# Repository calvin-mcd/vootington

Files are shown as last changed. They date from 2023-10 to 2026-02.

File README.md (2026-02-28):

# Vootington

The Vootington is an open source hall-effect pcb for the V4N keyboard.

The aim of this project is to offer a functional hardware Hall-effect reference project for the community. The project is not meant to offer the full aspects of firmware. I leave that to smart people to figure out.

The keyboard takes design cues from the Wooting keyboards, [the moonpad](https://github.com/RephlexZero/MoonPad) and [the void switch keyboards](https://github.com/riskable/void_switch_65_pct) from riskable.

## Layout

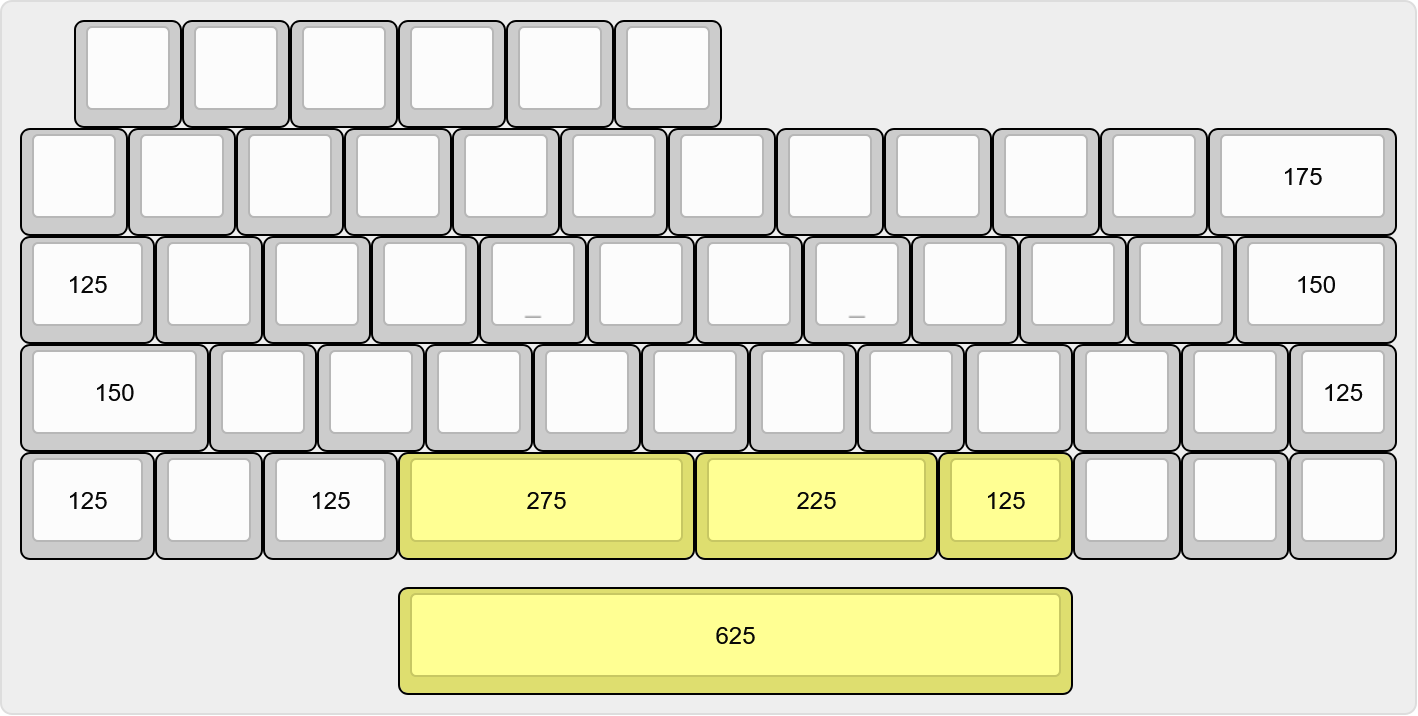
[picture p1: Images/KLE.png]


[Link](http://www.keyboard-layout-editor.com/#/gists/a01bb022278fa95758b773367ecef891)

## Firmware

The basic firmware included in the folder is experimental and designed by KarlK90. Their work can be found here:
https://github.com/KarlK90/qmk_firmware/tree/feature/vootington/keyboards/calvin0563/vootington

Pete is currently developing more advanced HE firmware for zmk. Keep your eyes on that:
https://github.com/petejohanson/vootington-zmk-config

**beware!!!**

The hardware configuration for rgb on the vootington is currently not supported by zmk, which means no rgb with the zmk firmware.

## Todo

- [ ] create advanced firmware with full HE functionality

## Disclaimer

This PCB has been fully tested and is confirmed to work. However, no-one involved in this project is responsible for any usage issues that may arise. Order at your own risk. Feel free to edit, modify and otherwise utilise these files.

## License

This project is released under the GPL v3 License. Please refer to the LICENCE file.

## Credits

big thanks to KarlK90 for making the initial firmware and for supporting the hardware design of the keyboard.

another huge thanks to pete for writing zmk firmware for this!

As always big thanks also to the many people who helped to inspire this board!

Any questions, contact Calvin0563 on Discord.

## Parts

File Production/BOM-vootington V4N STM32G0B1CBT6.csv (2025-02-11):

Comment | Designator | Footprint | LCSC | Quantity
330 Ohm | R4 | R_0402_1005Metric | C105875 | 1
1uF | C55 | C_0402_1005Metric | C106254 | 1
Alps SKRK | SW1,SW2 | SW_Push_SPST_NO_Alps_SKRK | C115351 | 2
1k OHM 100mhz | FB1 | Fuse_0402_1005Metric | C1236503 | 1
33 Ohm | R1,R2 | R_0402_1005Metric | C137880 | 2
10nF | C54 | C_0402_1005Metric | C1524 | 1
JST SH | J3 | JST_SH_SM04B-SRSS-TB_1x04-1MP_P1.00mm_Horizontal | C160404 | 1
10k | R3,R5,R6 | R_0402_1005Metric | C25744 | 3
5.1k | R7,R8 | R_0402_1005Metric | C25905 | 2
PRTR5V0U2X | U55 | SOT-143 | C2827688 | 1
STM32G0B1CBTx | U53 | LQFP-48_7x7mm_P0.5mm | C2847904 | 1
AP40P05 | Q1 | SOT-23 | C2886385 | 1
SLSS49E-3 | U1,U10,U11,U12,U13,U14,U15,U16,U17,U18,U19,U2,U20,U21,U22,U23,U24,U25,U26,U27,U28,U29,U3,U30,U31,U32,U33,U34,U35,U36,U37,U38,U39,U4,U40,U41,U42,U43,U44,U45,U46,U47,U48,U49,U5,U50,U51,U52,U6,U7,U8,U9 | SOT-23 | C2904393 | 52
SMF9.0CA | D_PWR1 | D_SOD-123 | C2980405 | 1
USB_C sink board 1.3mm | J2 | USB_C_Receptacle_HRO_TYPE-C-31-M-12 | C3019717 | 1
AP2112K-3.3 | U54 | SOT-23-5 | C3021085 | 1
100nF | C1,C10,C100,C101,C102,C103,C104,C105,C106,C107,C108,C109,C11,C110,C111,C112,C113,C114,C115,C116,C117,C118,C119,C12,C120,C121,C122,C123,C124,C13,C14,C15,C16,C17,C18,C19,C2,C20,C21,C22,C23,C24,C25,C26,C27,C28,C29,C3,C30,C31,C32,C33,C34,C35,C36,C37,C38,C39,C4,C40,C41,C42,C43,C44,C45,C46,C47,C48,C49,C5,C50,C51,C52,C53,C56,C6,C61,C62,C63,C64,C65,C66,C67,C68,C69,C7,C70,C71,C72,C73,C74,C75,C76,C77,C78,C79,C8,C80,C81,C82,C83,C84,C85,C86,C87,C88,C89,C9,C90,C91,C92,C93,C94,C95,C96,C97,C98,C99 | C_0402_1005Metric | C307331 | 118
YS-SK6803MINI-E | D1,D10,D11,D12,D13,D14,D15,D16,D17,D18,D19,D2,D20,D21,D22,D23,D24,D25,D26,D27,D28,D29,D3,D30,D31,D32,D33,D34,D35,D36,D37,D38,D39,D4,D40,D41,D42,D43,D44,D45,D46,D47,D48,D49,D5,D50,D51,D52,D53,D54,D55,D6,D7,D8,D9 | SK6803-MINI-E | C5242955 | 55
10uF | C57,C58,C59,C60 | C_0402_1005Metric | C52923 | 4
74HC4051 | U57,U58,U59,U60,U61,U62,U63 | TSSOP16 | C5645 | 7
500mA | F1 | Fuse_1206_3216Metric | C70076 | 1
74AHCT1G125 | U56 | TSOT-23-5 | C7468 | 1

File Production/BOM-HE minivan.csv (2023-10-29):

Comment | Designator | Footprint | LCSC
SKQGABE010 | SW1 | SW_SPST_SKQG_WithoutStem | C115351
ASMD1206-150 | F2 | Fuse_1206_3216Metric | C135341
JST SH | J1 | JST_SH_SM04B-SRSS-TB_1x04-1MP_P1.00mm_Horizontal | C160404
10k | R5 | R_0402_1005Metric | C25744
5.1k | R3,R4 | R_0402_1005Metric | C25905
PRTR5V0U2X | U58 | SOT-143 | C2827688
SLSS49E-3 | U10,U11,U12,U13,U14,U15,U16,U17,U18,U19,U2,U20,U21,U22,U23,U24,U25,U26,U27,U28,U29,U30,U31,U32,U33,U34,U35,U36,U37,U38,U39,U4,U40,U41,U42,U43,U44,U45,U47,U48,U49,U5,U50,U6,U7,U8,U9 | SOT-23 | C2904393
USB_C sink board 1.3mm | J2 | USB_C_Receptacle_HRO_TYPE-C-31-M-12 | C3019717
100nF | C1,C10,C11,C12,C2,C29,C3,C6 | C_0402_1005Metric | C307331
60R@100MHz | L1 | L_1206_3216Metric | C33600
SK6812MINI-E | D13,D14,D19,D2,D20,D25,D26,D31,D32,D37,D38,D44,D49,D7,D8 | LED_6028R | C5149201
SK6812MINI-E | D10,D11,D12,D15,D16,D17,D18,D21,D22,D23,D24,D27,D28,D29,D3,D30,D33,D34,D35,D36,D39,D4,D40,D41,D42,D45,D46,D47,D48,D5,D6,D9 | LED_6028R | C5183448
1uF | C4,C5 | C_0402_1005Metric | C52923
XC6206PxxxMR-Regulator_Linear | U52 | SOT-23 | C5446
74HC4051 | U51,U53,U54,U55,U56,U57 | TSSOP16 | C5645
74AHCT1G125 | U46 | TSOT-23-5 | C7468
STM32F072CBT6 | U59 | LQFP-48_7x7mm_P0.5mm | C81720
10uF | C13 | C_0603_1608Metric | C96446

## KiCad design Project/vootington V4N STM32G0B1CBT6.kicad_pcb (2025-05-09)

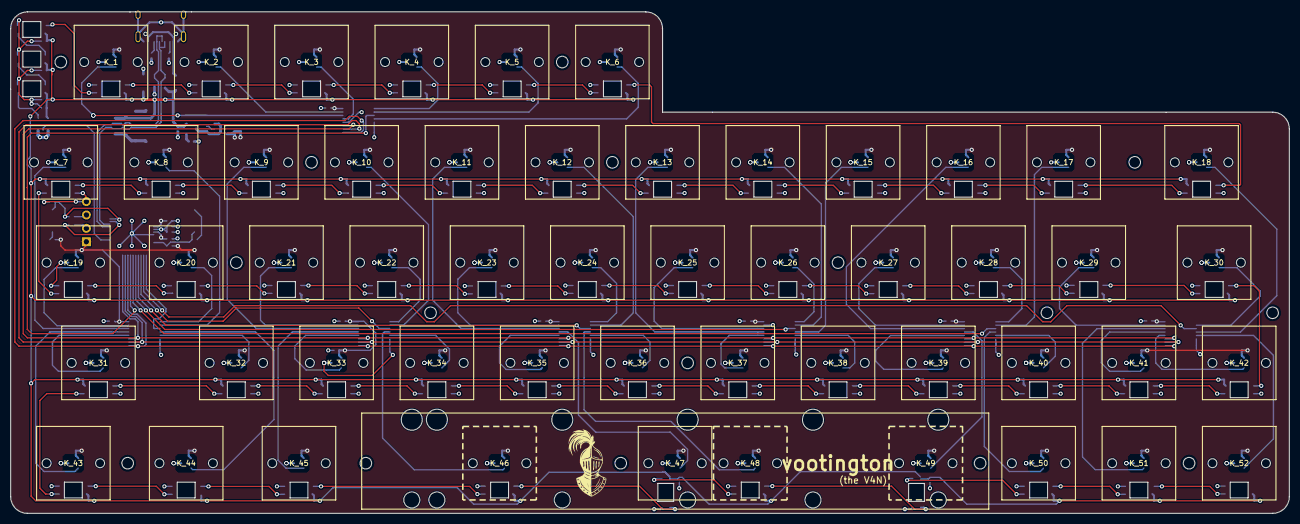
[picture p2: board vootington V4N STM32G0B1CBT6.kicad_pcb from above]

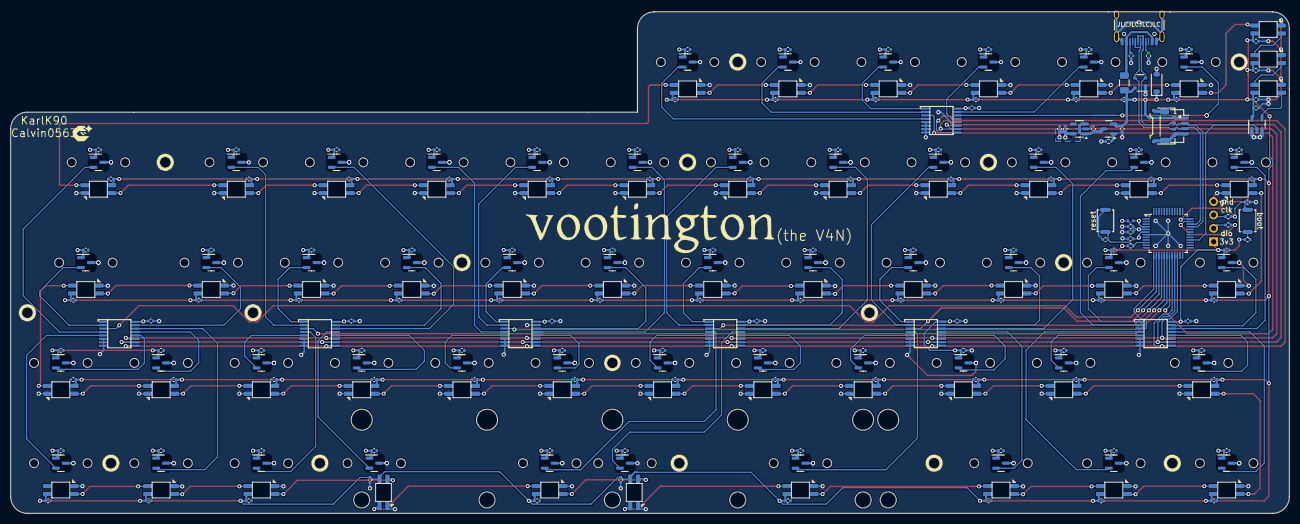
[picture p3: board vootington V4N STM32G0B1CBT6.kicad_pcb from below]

Board: 2 copper layers, 242.9 x 95.2 mm, 331 parts (260 on the bottom side), 135 nets.

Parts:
C1, C2, C3, C4, C5, C6, C7, C8, C9, C10, C11, C12, C13, C14, C15, C16, C17, C18, C19, C20, C21, C22, C23, C24, C25, C26, C27, C28, C29, C30, C31, C32, C33, C34, C35, C36, C37, C38, C39, C40, C41, C42, C43, C44, C45, C46, C47, C48, C49, C50, C51, C52, C53, C56, C60, C61, C62, C63, C64, C65, C66, C67, C68, C69, C70, C71, C72, C73, C74, C75, C76, C77, C78, C79, C80, C81, C82, C83, C84, C85, C86, C87, C88, C89, C90, C91, C92, C93, C94, C95, C96, C97, C98, C99, C100, C101, C102, C103, C104, C105, C106, C107, C108, C109, C110, C111, C112, C113, C114, C115, C116, C117: 100nF; C_0402_1005Metric
C54: 10nF; C_0402_1005Metric
C55: 1uF; C_0402_1005Metric
C57, C58: 10uF; C_0402_1005Metric
C59: 2.2uF; C_0402_1005Metric
C118, C119, C120, C121, C122, C123, C124: 100pF; C_0402_1005Metric
D1, D2, D3, D4, D5, D6, D7, D8, D9, D10, D11, D12, D13, D14, D15, D16, D17, D18, D19, D20, D21, D22, D23, D24, D25, D26, D27, D28, D29, D30, D31, D32, D33, D34, D35, D36, D37, D38, D39, D40, D41, D42, D43, D44, D45, D46, D47, D48, D49, D50, D51, D52, D53, D54, D55: YS-SK6803MINI-E; SK6803-MINI-E
D_PWR1: SMF9.0CA; D_SOD-123
F1: 500mA; Fuse_1206_3216Metric
FB1: 1k OHM 100mhz; Fuse_0402_1005Metric
H1, H2, H3, H4, H5, H6, H7, H8, H9, H10, H11, H12, H13, H14, H15, H16: MountingHole; HOLE_M2
J1: Conn_01x04; PinHeader_1x04_P2.54mm_Vertical
J2: USB_C sink board 1.3mm; USB_C_Receptacle_HRO_TYPE-C-31-M-12
J3: JST SH; JST_SH_SM04B-SRSS-TB_1x04-1MP_P1.00mm_Horizontal
J4: Pico EZmate; Molex_Pico-EZmate_78171-0004_1x04-1MP_P1.20mm_Vertical
K_1, K_2, K_3, K_4, K_5, K_6, K_7, K_8, K_9, K_10, K_11, K_12, K_13, K_14, K_15, K_16, K_17, K_18, K_19, K_20, K_21, K_22, K_23, K_24, K_25, K_26, K_27, K_28, K_29, K_30, K_31, K_32, K_33, K_34, K_35, K_36, K_37, K_38, K_39, K_40, K_41, K_42, K_43, K_44, K_45, K_46, K_47, K_48, K_49, K_50, K_51, K_52: KEYSW; Wooting_1.00u
Q1: AP40P05; SOT-23
R1, R2: 33 Ohm; R_0402_1005Metric
R3, R5, R6: 10k; R_0402_1005Metric
R4: 330 Ohm; R_0402_1005Metric
R7, R8: 5.1k; R_0402_1005Metric
S1: MX_stab; STAB_MX_2.75u
S2: MX_stab; STAB_MX_6.25u
S3: MX_stab; STAB_MX_2.25u
SW1, SW2: Alps SKRK; SW_Push_SPST_NO_Alps_SKRK
U1, U2, U3, U4, U5, U6, U7, U8, U9, U10, U11, U12, U13, U14, U15, U16, U17, U18, U19, U20, U21, U22, U23, U24, U25, U26, U27, U28, U29, U30, U31, U32, U33, U34, U35, U36, U37, U38, U39, U40, U41, U42, U43, U44, U45, U46, U47, U48, U49, U50, U51, U52: SLSS49E-3; SOT-23
U53: STM32G0B1CBTx; LQFP-48_7x7mm_P0.5mm
U54: AP2112K-3.3; SOT-23-5
U55: PRTR5V0U2X; SOT-143
U56: 74AHCT1G125; TSOT-23-5
U57, U58, U59, U60, U61, U62, U63: 74HC4051; TSSOP16

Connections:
+3V3: C1.1, C2.1, C3.1, C4.1, C5.1, C6.1, C7.1, C8.1, C9.1, C10.1, C11.1, C12.1, C13.1, C14.1, C15.1, C16.1, C17.1, C18.1, C19.1, C20.1, C21.1, C22.1, C23.1, C24.1, C25.1, C26.1, C27.1, C28.1, C29.1, C30.1, C31.1, C32.1, C33.1, C34.1, C35.1, C36.1, C37.1, C38.1, C39.1, C40.1, C41.1, C42.1, C43.1, C44.1, C45.1, C46.1, C47.1, C48.1, C49.1, C50.1, C51.1, C52.1, C53.1, C58.2, C59.2, C118.1, C119.1, C120.1, C121.1, C122.1, C123.1, C124.1, FB1.1, J1.1, R3.1, R4.1, U1.1 (VDD), U2.1 (VDD), U3.1 (VDD), U4.1 (VDD), U5.1 (VDD), U6.1 (VDD), U7.1 (VDD), U8.1 (VDD), U9.1 (VDD), U10.1 (VDD), U11.1 (VDD), U12.1 (VDD), U13.1 (VDD), U14.1 (VDD), U15.1 (VDD), U16.1 (VDD), U17.1 (VDD), U18.1 (VDD), U19.1 (VDD), U20.1 (VDD), U21.1 (VDD), U22.1 (VDD), U23.1 (VDD), U24.1 (VDD), U25.1 (VDD), U26.1 (VDD), U27.1 (VDD), U28.1 (VDD), U29.1 (VDD), U30.1 (VDD), U31.1 (VDD), U32.1 (VDD), U33.1 (VDD), U34.1 (VDD), U35.1 (VDD), U36.1 (VDD), U37.1 (VDD), U38.1 (VDD), U39.1 (VDD), U40.1 (VDD), U41.1 (VDD), U42.1 (VDD), U43.1 (VDD), U44.1 (VDD), U45.1 (VDD), U46.1 (VDD), U47.1 (VDD), U48.1 (VDD), U49.1 (VDD), U50.1 (VDD), U51.1 (VDD), U52.1 (VDD), U53.4 (VBAT), U53.6 (VDD), U54.5 (VOUT), U57.16 (VCC), U58.16 (VCC), U59.16 (VCC), U60.16 (VCC), U61.16 (VCC), U62.16 (VCC), U63.16 (VCC)
+5V: C60.2, C61.1, C62.1, C63.1, C64.1, C65.2, C66.1, C67.1, C68.1, C69.1, C70.1, C71.1, C72.1, C73.1, C74.1, C75.1, C76.1, C77.1, C78.1, C79.1, C80.1, C81.1, C82.1, C83.1, C84.1, C85.1, C86.1, C87.1, C88.1, C89.1, C90.1, C91.1, C92.1, C93.1, C94.1, C95.1, C96.1, C97.1, C98.1, C99.1, C100.1, C101.1, C102.1, C103.1, C104.1, C105.1, C106.1, C107.1, C108.1, C109.1, C110.1, C111.1, C112.1, C113.1, C114.1, C115.1, C116.1, C117.1, D1.3 (VDD), D2.3 (VDD), D3.3 (VDD), D4.3 (VDD), D5.3 (VDD), D6.3 (VDD), D7.3 (VDD), D8.3 (VDD), D9.3 (VDD), D10.3 (VDD), D11.3 (VDD), D12.3 (VDD), D13.3 (VDD), D14.3 (VDD), D15.3 (VDD), D16.3 (VDD), D17.3 (VDD), D18.3 (VDD), D19.3 (VDD), D20.3 (VDD), D21.3 (VDD), D22.3 (VDD), D23.3 (VDD), D24.3 (VDD), D25.3 (VDD), D26.3 (VDD), D27.3 (VDD), D28.3 (VDD), D29.3 (VDD), D30.3 (VDD), D31.3 (VDD), D32.3 (VDD), D33.3 (VDD), D34.3 (VDD), D35.3 (VDD), D36.3 (VDD), D37.3 (VDD), D38.3 (VDD), D39.3 (VDD), D40.3 (VDD), D41.3 (VDD), D42.3 (VDD), D43.3 (VDD), D44.3 (VDD), D45.3 (VDD), D46.3 (VDD), D47.3 (VDD), D48.3 (VDD), D49.3 (VDD), D50.3 (VDD), D51.3 (VDD), D52.3 (VDD), D53.3 (VDD), D54.3 (VDD), D55.3 (VDD), D_PWR1.1 (A1), F1.2, J3.1, J4.1, Q1.2 (S), U55.4 (VCC), U56.5 (VCC)
/MCU/VREF: C54.1, C55.1, FB1.2, U53.5 (VREF+)
ADC0: U53.14 (PA3), U57.3 (A)
ADC1: U53.18 (PA7), U58.3 (A)
ADC2: U53.17 (PA6), U59.3 (A)
ADC3: U53.16 (PA5), U60.3 (A)
ADC4: U53.15 (PA4), U61.3 (A)
ADC5: U53.13 (PA2), U62.3 (A)
ADC6: U53.19 (PB0), U63.3 (A)
BOOT0: R2.1, R5.1, SW1.2, U53.36 (PA14)
D_N: J2.A7 (D-), J2.B7 (D-), J3.2, J4.2, U53.33 (PA11/PA9), U55.2 (I/O1)
D_P: J2.A6 (D+), J2.B6 (D+), J3.3, J4.3, U53.34 (PA12/PA10), U55.3 (I/O2)
GND: C1.2, C2.2, C3.2, C4.2, C5.2, C6.2, C7.2, C8.2, C9.2, C10.2, C11.2, C12.2, C13.2, C14.2, C15.2, C16.2, C17.2, C18.2, C19.2, C20.2, C21.2, C22.2, C23.2, C24.2, C25.2, C26.2, C27.2, C28.2, C29.2, C30.2, C31.2, C32.2, C33.2, C34.2, C35.2, C36.2, C37.2, C38.2, C39.2, C40.2, C41.2, C42.2, C43.2, C44.2, C45.2, C46.2, C47.2, C48.2, C49.2, C50.2, C51.2, C52.2, C53.2, C54.2, C55.2, C56.2, C57.1, C58.1, C59.1, C60.1, C61.2, C62.2, C63.2, C64.2, C65.1, C66.2, C67.2, C68.2, C69.2, C70.2, C71.2, C72.2, C73.2, C74.2, C75.2, C76.2, C77.2, C78.2, C79.2, C80.2, C81.2, C82.2, C83.2, C84.2, C85.2, C86.2, C87.2, C88.2, C89.2, C90.2, C91.2, C92.2, C93.2, C94.2, C95.2, C96.2, C97.2, C98.2, C99.2, C100.2, C101.2, C102.2, C103.2, C104.2, C105.2, C106.2, C107.2, C108.2, C109.2, C110.2, C111.2, C112.2, C113.2, C114.2, C115.2, C116.2, C117.2, C118.2, C119.2, C120.2, C121.2, C122.2, C123.2, C124.2, D1.1 (VSS), D2.1 (VSS), D3.1 (VSS), D4.1 (VSS), D5.1 (VSS), D6.1 (VSS), D7.1 (VSS), D8.1 (VSS), D9.1 (VSS), D10.1 (VSS), D11.1 (VSS), D12.1 (VSS), D13.1 (VSS), D14.1 (VSS), D15.1 (VSS), D16.1 (VSS), D17.1 (VSS), D18.1 (VSS), D19.1 (VSS), D20.1 (VSS), D21.1 (VSS), D22.1 (VSS), D23.1 (VSS), D24.1 (VSS), D25.1 (VSS), D26.1 (VSS), D27.1 (VSS), D28.1 (VSS), D29.1 (VSS), D30.1 (VSS), D31.1 (VSS), D32.1 (VSS), D33.1 (VSS), D34.1 (VSS), D35.1 (VSS), D36.1 (VSS), D37.1 (VSS), D38.1 (VSS), D39.1 (VSS), D40.1 (VSS), D41.1 (VSS), D42.1 (VSS), D43.1 (VSS), D44.1 (VSS), D45.1 (VSS), D46.1 (VSS), D47.1 (VSS), D48.1 (VSS), D49.1 (VSS), D50.1 (VSS), D51.1 (VSS), D52.1 (VSS), D53.1 (VSS), D54.1 (VSS), D55.1 (VSS), D_PWR1.2 (A2), J1.4, J2.A1 (GND), J2.A12 (GND), J2.B1 (GND), J2.B12 (GND), J2.S1 (SHIELD), J3.4, J3.MP (MountPin), J4.4, J4.MP (MountPin), R5.2, R6.1, R7.1, R8.1, SW2.2, U1.3 (GND), U2.3 (GND), U3.3 (GND), U4.3 (GND), U5.3 (GND), U6.3 (GND), U7.3 (GND), U8.3 (GND), U9.3 (GND), U10.3 (GND), U11.3 (GND), U12.3 (GND), U13.3 (GND), U14.3 (GND), U15.3 (GND), U16.3 (GND), U17.3 (GND), U18.3 (GND), U19.3 (GND), U20.3 (GND), U21.3 (GND), U22.3 (GND), U23.3 (GND), U24.3 (GND), U25.3 (GND), U26.3 (GND), U27.3 (GND), U28.3 (GND), U29.3 (GND), U30.3 (GND), U31.3 (GND), U32.3 (GND), U33.3 (GND), U34.3 (GND), U35.3 (GND), U36.3 (GND), U37.3 (GND), U38.3 (GND), U39.3 (GND), U40.3 (GND), U41.3 (GND), U42.3 (GND), U43.3 (GND), U44.3 (GND), U45.3 (GND), U46.3 (GND), U47.3 (GND), U48.3 (GND), U49.3 (GND), U50.3 (GND), U51.3 (GND), U52.3 (GND), U53.7 (VSS), U54.2 (GND), U55.1 (GND), U56.1, U56.3 (GND), U57.6 (~E), U57.7 (VEE), U57.8 (GND), U58.6 (~E), U58.7 (VEE), U58.8 (GND), U59.6 (~E), U59.7 (VEE), U59.8 (GND), U59.15 (A2), U60.6 (~E), U60.7 (VEE), U60.8 (GND), U61.6 (~E), U61.7 (VEE), U61.8 (GND), U62.6 (~E), U62.7 (VEE), U62.8 (GND), U63.5 (A5), U63.6 (~E), U63.7 (VEE), U63.8 (GND), U63.12 (A3)
K_1: U7.2 (OUT), U62.14 (A1)
K_2: U8.2 (OUT), U62.2 (A6)
K_3: U9.2 (OUT), U61.14 (A1)
K_4: U10.2 (OUT), U61.2 (A6)
K_5: U11.2 (OUT), U60.14 (A1)
K_6: U12.2 (OUT), U60.2 (A6)
K_7: U13.2 (OUT), U59.13 (A0)
K_8: U14.2 (OUT), U59.2 (A6)
K_9: U15.2 (OUT), U59.4 (A7)
K_10: U16.2 (OUT), U58.14 (A1)
K_11: U18.2 (OUT), U58.2 (A6)
K_12: U17.2 (OUT), U57.4 (A7)
K_13: U19.2 (OUT), U62.15 (A2)
K_14: U20.2 (OUT), U62.1 (A4)
K_15: U21.2 (OUT), U61.15 (A2)
K_16: U22.2 (OUT), U61.1 (A4)
K_17: U23.2 (OUT), U60.15 (A2)
K_18: U24.2 (OUT), U60.1 (A4)
K_19: U25.2 (OUT), U59.14 (A1)
K_20: U26.2 (OUT), U59.1 (A4)
K_21: U27.2 (OUT), U58.15 (A2)
K_22: U28.2 (OUT), U58.1 (A4)
K_23: U29.2 (OUT), U57.15 (A2)
K_24: U30.2 (OUT), U57.2 (A6)
K_25: U31.2 (OUT), U62.12 (A3)
K_26: U32.2 (OUT), U62.5 (A5)
K_27: U33.2 (OUT), U61.12 (A3)
K_28: U34.2 (OUT), U61.5 (A5)
K_29: U35.2 (OUT), U60.12 (A3)
K_30: U36.2 (OUT), U60.5 (A5)
K_31: U37.2 (OUT), U59.12 (A3)
K_32: U38.2 (OUT), U59.5 (A5)
K_33: U39.2 (OUT), U58.12 (A3)
K_34: U40.2 (OUT), U58.5 (A5)
K_35: U41.2 (OUT), U57.13 (A0)
K_36: U42.2 (OUT), U57.12 (A3)
K_37: U43.2 (OUT), U62.13 (A0)
K_38: U44.2 (OUT), U62.4 (A7)
K_39: U45.2 (OUT), U61.13 (A0)
K_40: U46.2 (OUT), U61.4 (A7)
K_41: U47.2 (OUT), U60.13 (A0)
K_42: U48.2 (OUT), U60.4 (A7)
K_43: U49.2 (OUT), U58.13 (A0)
K_44: U50.2 (OUT), U58.4 (A7)
K_45: U51.2 (OUT), U57.14 (A1)
K_46: U52.2 (OUT), U57.5 (A5)
K_48: U1.2 (OUT), U63.14 (A1)
K_49: U2.2 (OUT), U63.15 (A2)
K_50: U3.2 (OUT), U63.13 (A0)
K_51: U4.2 (OUT), U63.1 (A4)
K_52: U5.2 (OUT), U63.2 (A6)
K_53: U6.2 (OUT), U63.4 (A7)
NRST: C56.1, R3.2, SW2.1, U53.10 (PF2)
unnamed: D1.4 (DOUT), D2.2 (DIN)
unnamed: D2.4 (DOUT), D3.2 (DIN)
unnamed: D3.4 (DOUT), D4.2 (DIN)
unnamed: D4.4 (DOUT), D5.2 (DIN)
unnamed: D5.4 (DOUT), D6.2 (DIN)
unnamed: D6.4 (DOUT), D7.2 (DIN)
unnamed: D7.4 (DOUT), D8.2 (DIN)
unnamed: D8.4 (DOUT), D9.2 (DIN)
unnamed: D9.4 (DOUT), D10.2 (DIN)
unnamed: D10.4 (DOUT), D11.2 (DIN)
unnamed: D11.4 (DOUT), D12.2 (DIN)
unnamed: D12.4 (DOUT), D13.2 (DIN)
unnamed: D13.4 (DOUT), D14.2 (DIN)
unnamed: D14.4 (DOUT), D15.2 (DIN)
unnamed: D15.4 (DOUT), D16.2 (DIN)
unnamed: D16.4 (DOUT), D17.2 (DIN)
unnamed: D17.4 (DOUT), D18.2 (DIN)
unnamed: D18.4 (DOUT), D19.2 (DIN)
unnamed: D19.4 (DOUT), D20.2 (DIN)
unnamed: D20.4 (DOUT), D21.2 (DIN)
unnamed: D21.4 (DOUT), D33.2 (DIN)
unnamed: D22.2 (DIN), D23.4 (DOUT)
unnamed: D22.4 (DOUT), D34.2 (DIN)
unnamed: D23.2 (DIN), D24.4 (DOUT)
unnamed: D24.2 (DIN), D25.4 (DOUT)
unnamed: D25.2 (DIN), D26.4 (DOUT)
unnamed: D26.2 (DIN), D27.4 (DOUT)
unnamed: D27.2 (DIN), D28.4 (DOUT)
unnamed: D28.2 (DIN), D29.4 (DOUT)
unnamed: D29.2 (DIN), D30.4 (DOUT)
unnamed: D30.2 (DIN), D31.4 (DOUT)
unnamed: D31.2 (DIN), D32.4 (DOUT)
unnamed: D32.2 (DIN), D33.4 (DOUT)
unnamed: D34.4 (DOUT), D35.2 (DIN)
unnamed: D35.4 (DOUT), D36.2 (DIN)
unnamed: D36.4 (DOUT), D37.2 (DIN)
unnamed: D37.4 (DOUT), D38.2 (DIN)
unnamed: D38.4 (DOUT), D39.2 (DIN)
unnamed: D39.4 (DOUT), D40.2 (DIN)
unnamed: D40.4 (DOUT), D41.2 (DIN)
unnamed: D41.4 (DOUT), D42.2 (DIN)
unnamed: D42.4 (DOUT), D43.2 (DIN)
unnamed: D43.4 (DOUT), D44.2 (DIN)
unnamed: D44.4 (DOUT), D45.2 (DIN)
unnamed: D45.4 (DOUT), D55.2 (DIN)
unnamed: D46.2 (DIN), D47.4 (DOUT)
unnamed: D47.2 (DIN), D48.4 (DOUT)
unnamed: D48.2 (DIN), D49.4 (DOUT)
unnamed: D49.2 (DIN), D50.4 (DOUT)
unnamed: D50.2 (DIN), D51.4 (DOUT)
unnamed: D51.2 (DIN), D52.4 (DOUT)
unnamed: D52.2 (DIN), D53.4 (DOUT)
unnamed: D53.2 (DIN), D54.4 (DOUT)
unnamed: D54.2 (DIN), D55.4 (DOUT)
unnamed: J1.2, R1.2
unnamed: J1.3, R2.2
unnamed: J2.A5 (CC1), R7.2
unnamed: J2.B5 (CC2), R8.2
unnamed: C57.2, Q1.3 (D), U54.1 (VIN), U54.3 (EN)
unnamed: Q1.1 (G), R6.2
unnamed: R4.2, SW1.1
RGB: D1.2 (DIN), U56.4
RGB MCU: U53.28 (PA8), U56.2
SELECT0: U53.22 (PB10), U57.11 (S0), U58.11 (S0), U59.11 (S0), U60.11 (S0), U61.11 (S0), U62.11 (S0), U63.11 (S0)
SELECT1: U53.21 (PB2), U57.10 (S1), U58.10 (S1), U59.10 (S1), U60.10 (S1), U61.10 (S1), U62.10 (S1), U63.10 (S1)
SELECT2: U53.20 (PB1), U57.9 (S2), U58.9 (S2), U59.9 (S2), U60.9 (S2), U61.9 (S2), U62.9 (S2), U63.9 (S2)
SWDIO: R1.1, U53.35 (PA13)
VBUS: F1.1, J2.A4 (VBUS), J2.A9 (VBUS), J2.B4 (VBUS), J2.B9 (VBUS)

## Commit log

2023-08-20 deleted caps, res from moon project
    [MCU.kicad_sch, USB&Power.kicad_sch, rgb.kicad_sch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]
2023-08-24 vootvan progress
    [MCU.kicad_sch, rgb.kicad_sch, vootvan.kicad_sch]
2023-08-29 continue progress
    [MCU.kicad_sch, vootvan.kicad_pcb, vootvan.kicad_sch]
2023-09-15 project folder update
    [MCU.kicad_sch, USB&Power.kicad_sch, coriander.dxf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]
2023-09-24 created production files
    [BOM-vootington.csv, rgb.kicad_sch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]
2023-09-25 production files, back silkscreen
    [vootington-B_Cu.gbr, vootington-B_Fab.gbr, vootington-B_Mask.gbr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]
2023-10-01 created v4n pcb, finished routing
    [MCU gaming.kicad_sch, MCU.kicad_sch, USB&Power.kicad_sch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]
2023-10-11 updated VAN and V4N projects
    [MCU V4N.kicad_sch, MCU VAN.kicad_sch, MCU gaming.kicad_sch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]
2023-10-29 created plates and production files for protos
    [BOM-HE V4N.csv, BOM-HE minivan.csv, BOM-vootington V4N.csv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]
2023-12-02 rgb footprints changed, fresh gerbers, production
    [BOM-vootington V4N.csv, BOM-vootington VAN.csv, USB&Power.kicad_sch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]
2024-05-07 pin revision
    [MCU V4N.kicad_sch, MCU VAN.kicad_sch, Minivan plate.kicad_pcb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]
2024-08-28 revision work
    [MCU V4N.kicad_sch, USB&Power.kicad_sch, multi V4N.kicad_sch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]
2025-01-05 g0b1 revision added
    [MCU V4N STM32G0B1CBT6.kicad_sch, USB&Power STM32G0B1CBT6.kicad_sch, USB&Power V2.kicad_sch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]
2025-02-11 revision proto ready
    folder clean up
    [BOM-vootington V4N STM32G0B1CBT6.csv, BOM-vootington V4N.csv, BOM-vootington VAN.csv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]
2025-03-23 production files pcb&plate
    before second order
    [BOM-vootington V4N STM32G0B1CBT6.csv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]
2025-05-03 project clean up
    [V4N plate-B_Cu.gbr, V4N plate-B_Mask.gbr, V4N plate-B_Paste.gbr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]
2025-05-09 power error fix
    [MCU V4N STM32G0B1CBT6.kicad_sch, USB&Power STM32G0B1CBT6.kicad_sch, vootington V4N STM32G0B1CBT6.kicad_pcb]
2026-02-21 update repo for release
    [BOM-vootington V4N.csv, BOM-vootington VAN.csv, vootington V4N PROTO plate.kicad_pcb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]
